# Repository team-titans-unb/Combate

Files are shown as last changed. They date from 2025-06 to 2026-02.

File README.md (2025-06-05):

# 🤖 Combate ⚔️

Bem-vindo ao repositório de documentação e firmware para robôs de combate da Equipe Titans! Este projeto organiza todas as informações técnicas, designs e códigos relacionados aos nossos robôs de combate categorizados por classes de peso. 🏗️💻

## 🗂️ Estrutura 

A seguir segue um exemplo da estrutura organizacional:
```
├── 🐞 Beetleweight/
│ ├── Robo_Alpha/
│ │ ├── 📄 Documentacao/
| | | ├── 📟 Eletrônica/
| | | ├── 📸 Imagens/
| | | └── ⚙️ Mecânica/
│ │ ├── 💾 Firmware/
│ │ └── 📌 README.md
│ └── Robo_Beta/
│ │ ├── 📄 Documentacao/
| | | ├── 📟 Eletrônica/
| | | ├── 📸 Imagens/
| | | └── ⚙️ Mecânica/
│ │ ├── 💾 Firmware/
│ │ └── 📌 README.md
├── 🐜 Antweight/
└── 📌 README.md (este arquivo)
```
## 🏷️ Categorias Disponíveis

Por enquanto, desevolvemos apenas robôs da categoria Beetleweight (1.36kg).
*(Pastas serão criadas conforme novos robôs forem desenvolvidos)* 🔄

## 🔧 Conteúdo Padrão por Robô

Cada robô deve ter documentado:
- 🧠 Firmware customizado
- 🔌 Esquemáticos eletrônicos
- 🛠️ 'Computer Aided Design' final renderizado

O README.md de cada diretório deve conter uma descrição curta das especificações do robô

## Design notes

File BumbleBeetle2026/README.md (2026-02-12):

# BumbleBeetle 2.0 (2026)
  
<p align="center">
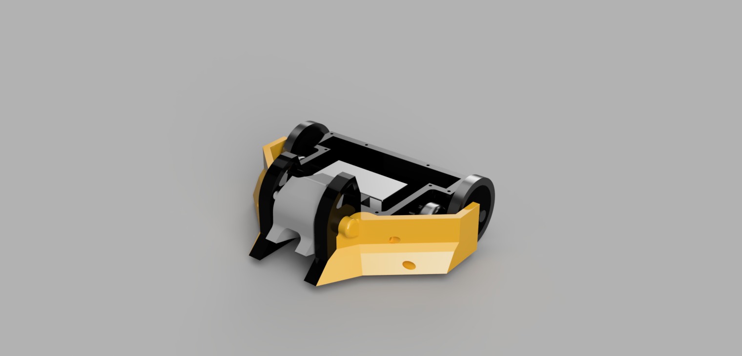
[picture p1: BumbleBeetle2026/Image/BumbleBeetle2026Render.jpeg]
  
</p>  

### ⚙️ Especificações Técnicas

- **Categoria:** Beetleweight (1,36kg)  
- **Arma:** Tambor giratório horizontal 70mm x 40mm
- **Motor da arma:** Surpass hobby C2830 - 750KV
- **Tração:** Rodas de PU55
- **Bateria:** FunFly 4S 100C 1550mAh

### 📟 Eletrônica

- **Rádio Controle:** -- 
- **Motor de Locomoção:** 2x Surpass Hobby 1700KV 
- **ESC da arma:** Flycolor Raptor5 50A
- **ESC de Locomoção:** --

### ⚡ Principais Características

- **Arma de aço 4340 temperado**
- Chassi Impresso de TPU

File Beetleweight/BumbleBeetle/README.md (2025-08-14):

# 🤖 Bumblebeetle - Beetleweight Combat Robot
  O projeto 'BumbleBeetle' é um robô de combate da categoria de 1.36kg. Tal projeto, é composto por uma pequena arma giratória caracterizada como DRUMS.  
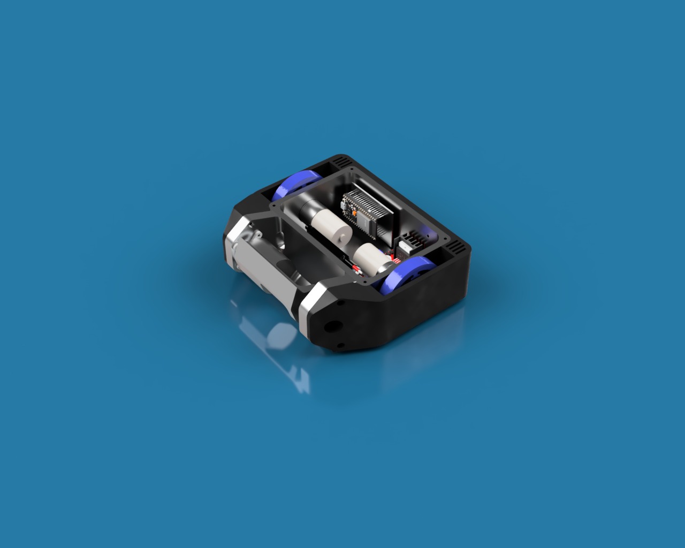
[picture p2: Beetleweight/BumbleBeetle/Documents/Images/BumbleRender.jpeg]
    

### ⚙️ Especificações Técnicas

- **Categoria:** Beetleweight (1,36kg)  
- **Arma:** Tambor giratório horizontal  
- **Motor da arma:** PropDrive 28-36 3000kv  
- **Tração:** 2 rodas de silocone  
- **Bateria:** LiPo 3S 11.1V 2200mAH

### 📟 Eletrônica

- **Microcontrolador:** ESP32 DevKit V1  
- **Controle:** Via Bluetooth usando um controle de PS3  
- **Motor de Locomoção:** 2x Motor com Caixa de Redução 12V 500RPM  
- **ESC:** Flysky Raptor5 50A

### ⚡ Principais Características

- **Arma de aço 1045 com têmpera**
- Chassi Impresso de TPU

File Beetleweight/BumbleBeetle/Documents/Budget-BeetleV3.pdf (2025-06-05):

Nome do item | Qtd | Valor Unitário | Taxa de Importação | Frete | Desconto | Custo Total | Observações | Outras Observações
Bateria Lipo 3s 2200mah | 1 | R$ 129,99 | R$ 0,00 | R$ 0,00 | R$ 0,00 | R$ 129,99 | | Este orçamento está sujeito a alterações
Usinagem da Arma | 1 | R$ 300,00 | R$ 0,00 | R$ 0,00 | R$ 0,00 | R$ 300,00 | Preço pode variar, mas é na faixa dos 300 reais | O corpo do robô será em alumínio 6065T
Filamento Tritan | 1 | R$ 219,84 | R$ 0,00 | R$ 0,00 | R$ 0,00 | R$ 219,84
Filamento TPU | 1 | R$ 119,90 | R$ 0,00 | R$ 0,00 | R$ 0,00 | R$ 119,90
ESC 60A BLHELI Brushless ReadyTosky | 1 | R$ 160,51 | R$ 0,00 | R$ 26,85 | R$ 0,00 | R$ 187,36 | Já comprado e valor com impostos
Carregador Duplo para Bateria Li-Ion 18650 | 1 | R$ 33,25 | R$ 0,00 | R$ 0,00 | R$ 0,00 | R$ 33,25 | Já comprado
Inscrição RCX | 1 | R$ 120,00 | R$ 0,00 | R$ 0,00 | R$ 0,00 | R$ 120,00 | Já comprado
Tarugo de aço 1045 | 1 | R$ 70,00 | R$ 0,00 | R$ 0,00 | R$ 0,00 | R$ 70,00 | Já comprado
Placa de Fibra de Vidro Universal (10 x 10 cm) Face Simples | 2 | R$ 13,23 | R$ 0,00 | R$ 0,00 | R$ 0,00 | R$ 26,46
Motor DC 12V | 2 | R$ 59,90 | R$ 0,00 | R$ 40,12 | R$ 8,00 | R$ 151,92 | Já comprado
Rolamento cerâmico VICAN | 1 | R$ 144,90 | R$ 0,00 | R$ 0,00 | R$ 0,00 | R$ 144,90 | Já comprado
| | | | | | Total
R$ 1.503,62

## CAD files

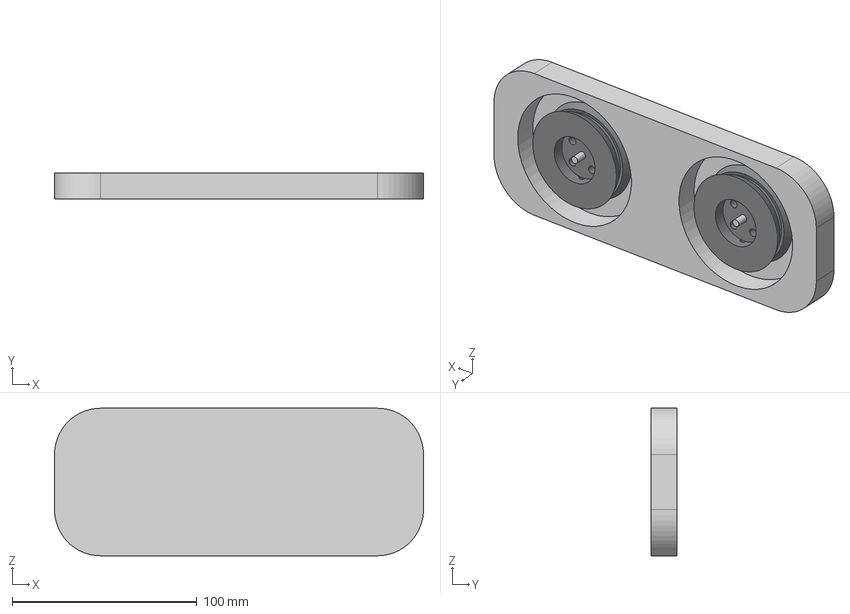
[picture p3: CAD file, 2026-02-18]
Beetleweight/BumbleBeetle/Documents/Mechanics/Molde das rodas Beetle 2025.step
200.0 x 14.0 x 80.0 mm
Nova Roda do Beetle em TPU e PU55
Nova Roda do Beetle em TPU e PU55 v8(Espelhar)

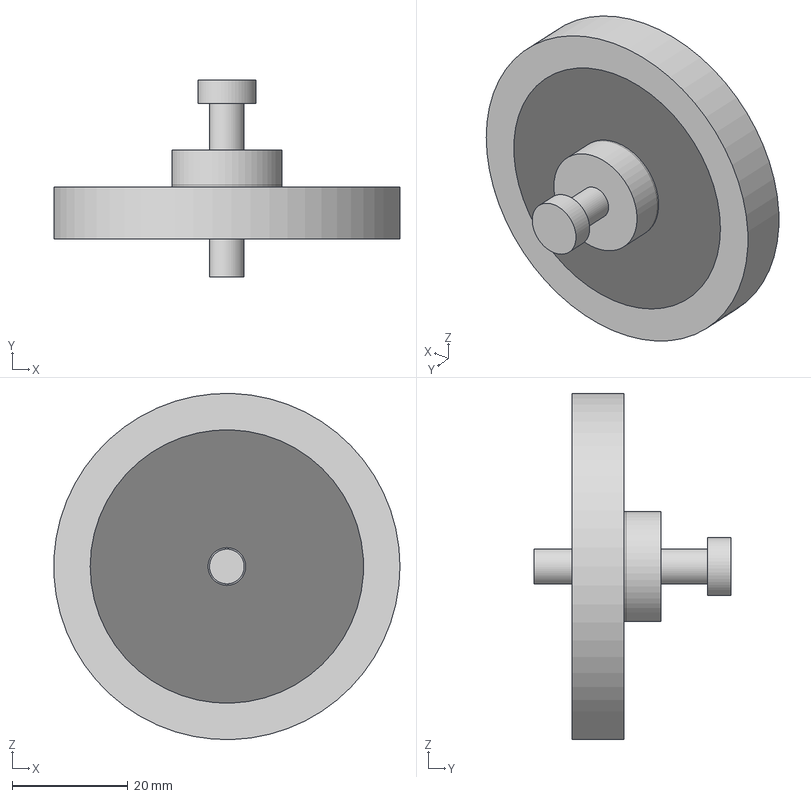
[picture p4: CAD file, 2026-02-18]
BumbleBeetle2026/Mechanic/Roda para loc. Tangenciada 2026.step
59.8 x 34.0 x 59.8 mm
ROLAMENTO 626 x 2

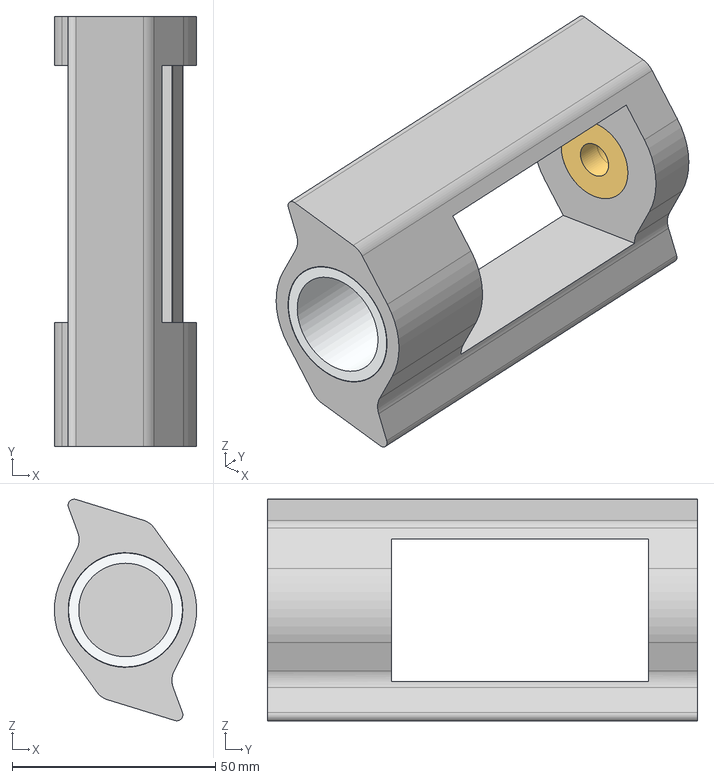
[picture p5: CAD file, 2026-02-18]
Beetleweight/BumbleBeetle/Documents/Mechanics/hubmotor 2025.step
35.0 x 105.7 x 54.5 mm
Imã do motor
rolamento 19 externo, 8 interno e 6 espessura x 2

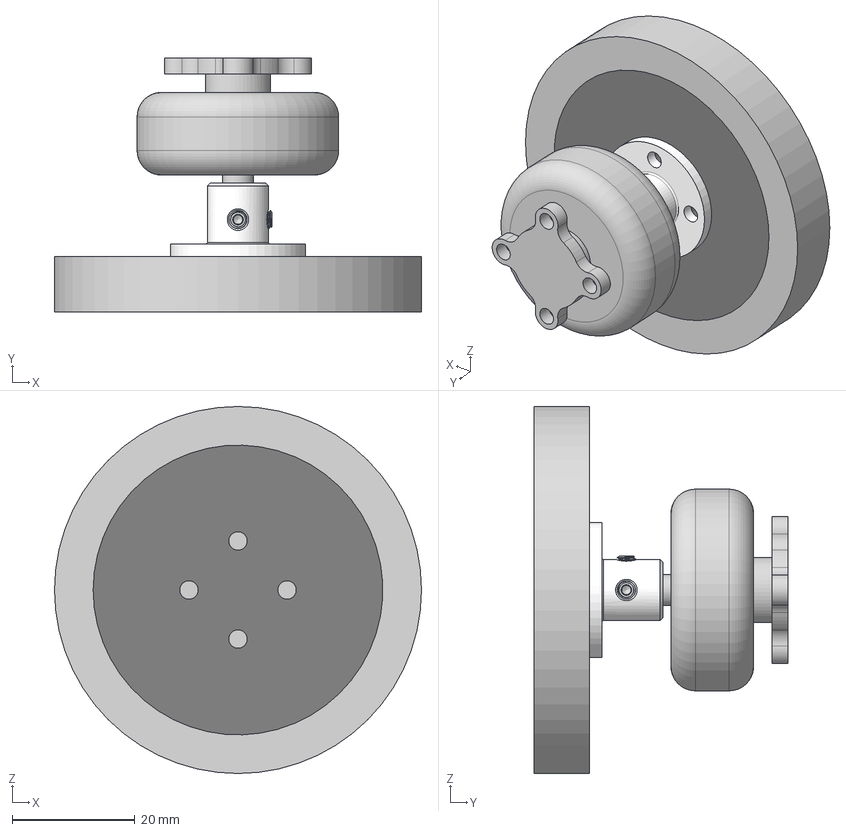
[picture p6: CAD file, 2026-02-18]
BumbleBeetle2026/Mechanic/Roda para Acoplador de eixo 2026.step
59.8 x 41.4 x 59.9 mm
91390A097 x 2
Surpass Hobby BAT 1700Kv

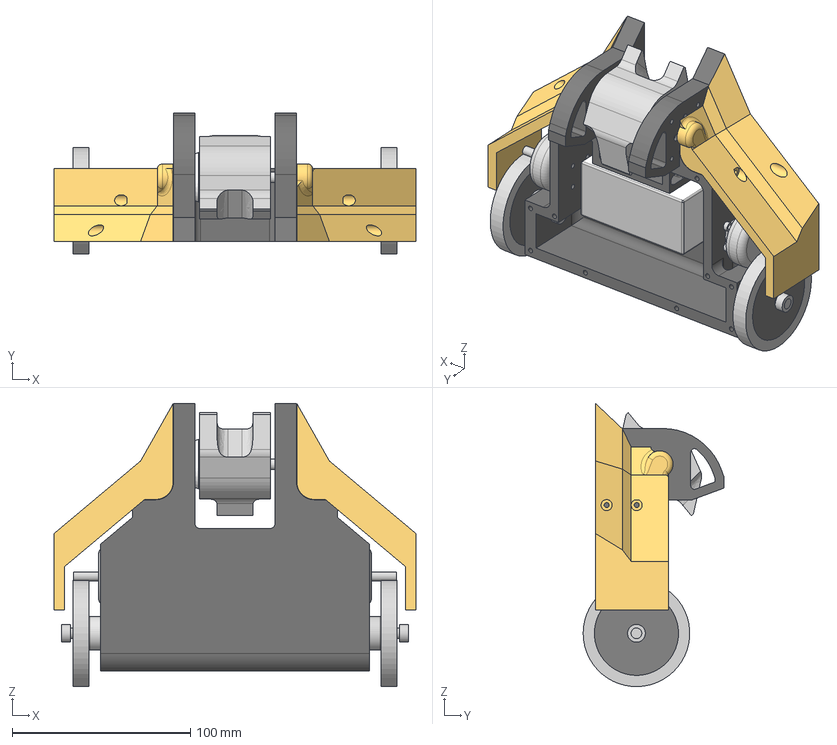
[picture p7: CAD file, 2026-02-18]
BumbleBeetle2026/Mechanic/Protótipo Plano A Loc. Tangenciado 2026.step
203.2 x 79.0 x 159.0 mm
Surpass Hobby BAT 1700Kv
FunFly 4S 1550mah
SURPASS HOBBY 2212 C2830 850KV_BRKT-01
SURPASS HOBBY 2212 C2830 850KV_BODY
SURPASS HOBBY 2212 C2830 850KV
ROLAMENTO 626 x 4
eixo retificado
Surpass Hobby BAT 1700Kv v4(Espelhar) (1)
ROLAMENTO 626 v1(Espelhar) x 2
Porca parafuso M6
Porca parafuso M6 v1(Espelhar)

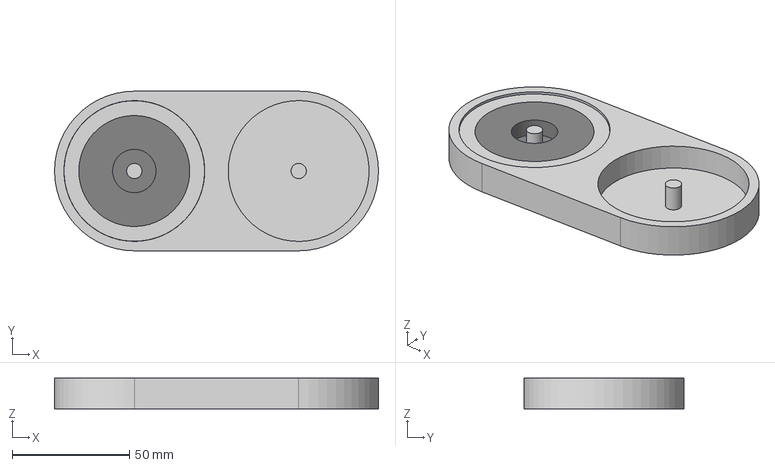
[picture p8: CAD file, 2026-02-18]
BumbleBeetle2026/Mechanic/Molde Para Loc Tangenciada (Imprimir em ABS!!)).step
138.0 x 68.0 x 13.0 mm

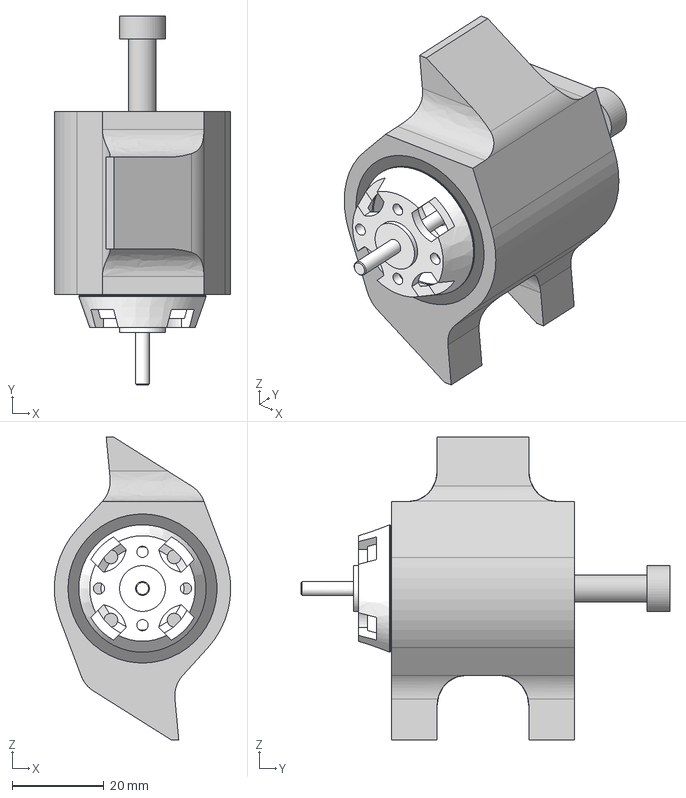
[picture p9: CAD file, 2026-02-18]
BumbleBeetle2026/Mechanic/HUBMOTOR bumbleBeetleV2 com novo motor 2026.step
38.5 x 80.5 x 66.0 mm
SURPASS HOBBY 2212 C2830 850KV_BODY
SURPASS HOBBY 2212 C2830 850KV
ROLAMENTO 626 x 2
eixo retificado

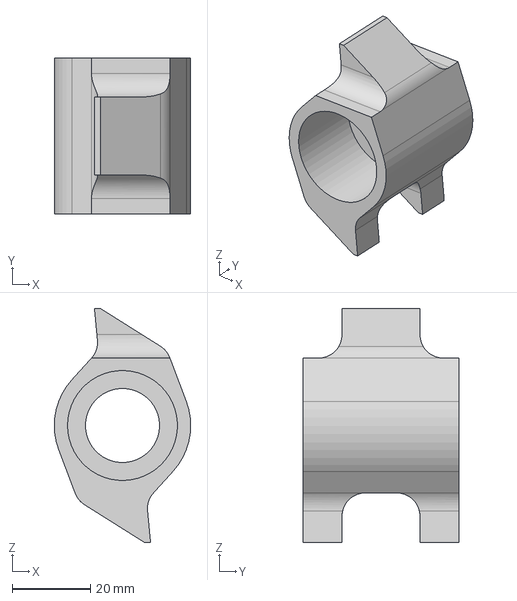
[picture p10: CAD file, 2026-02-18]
BumbleBeetle2026/Mechanic/HUBMOTOR bumble V2.step
35.0 x 40.0 x 60.0 mm

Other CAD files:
BumbleBeetle2026/Mechanic/Molde Para acoplador de eixo (Imprimir em ABS!!)).step

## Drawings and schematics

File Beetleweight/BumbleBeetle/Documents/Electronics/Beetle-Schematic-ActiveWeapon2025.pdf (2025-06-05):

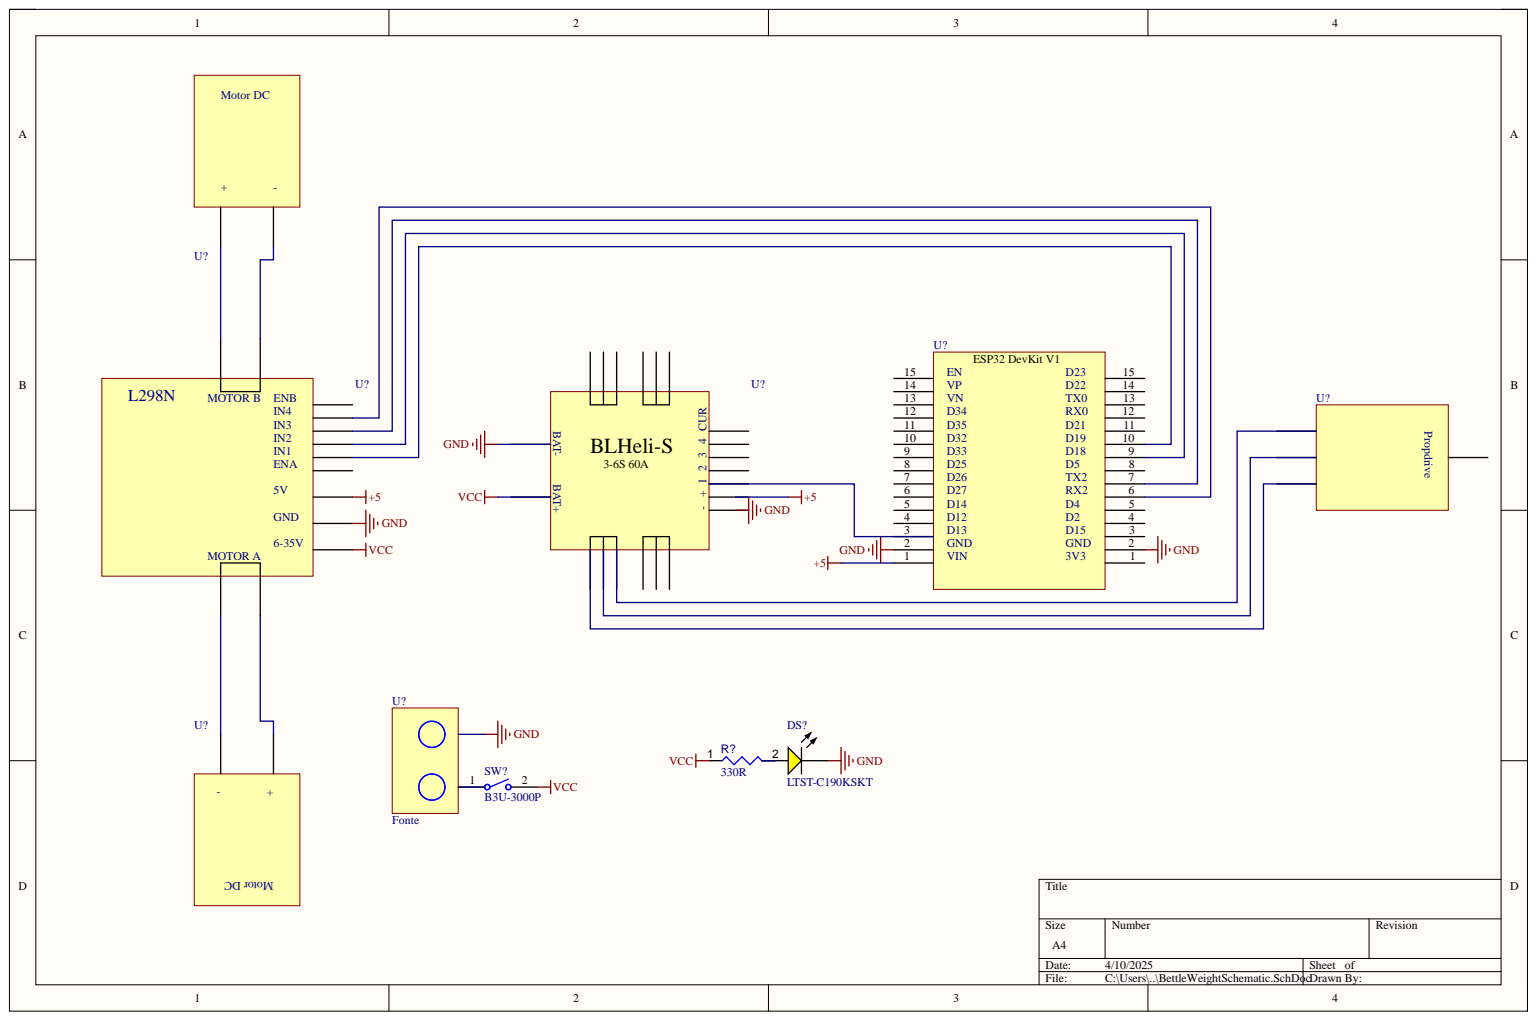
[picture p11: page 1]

D27 RX2 D14 D4 D12 D2 D13 D15 GND GND VI N 3V3

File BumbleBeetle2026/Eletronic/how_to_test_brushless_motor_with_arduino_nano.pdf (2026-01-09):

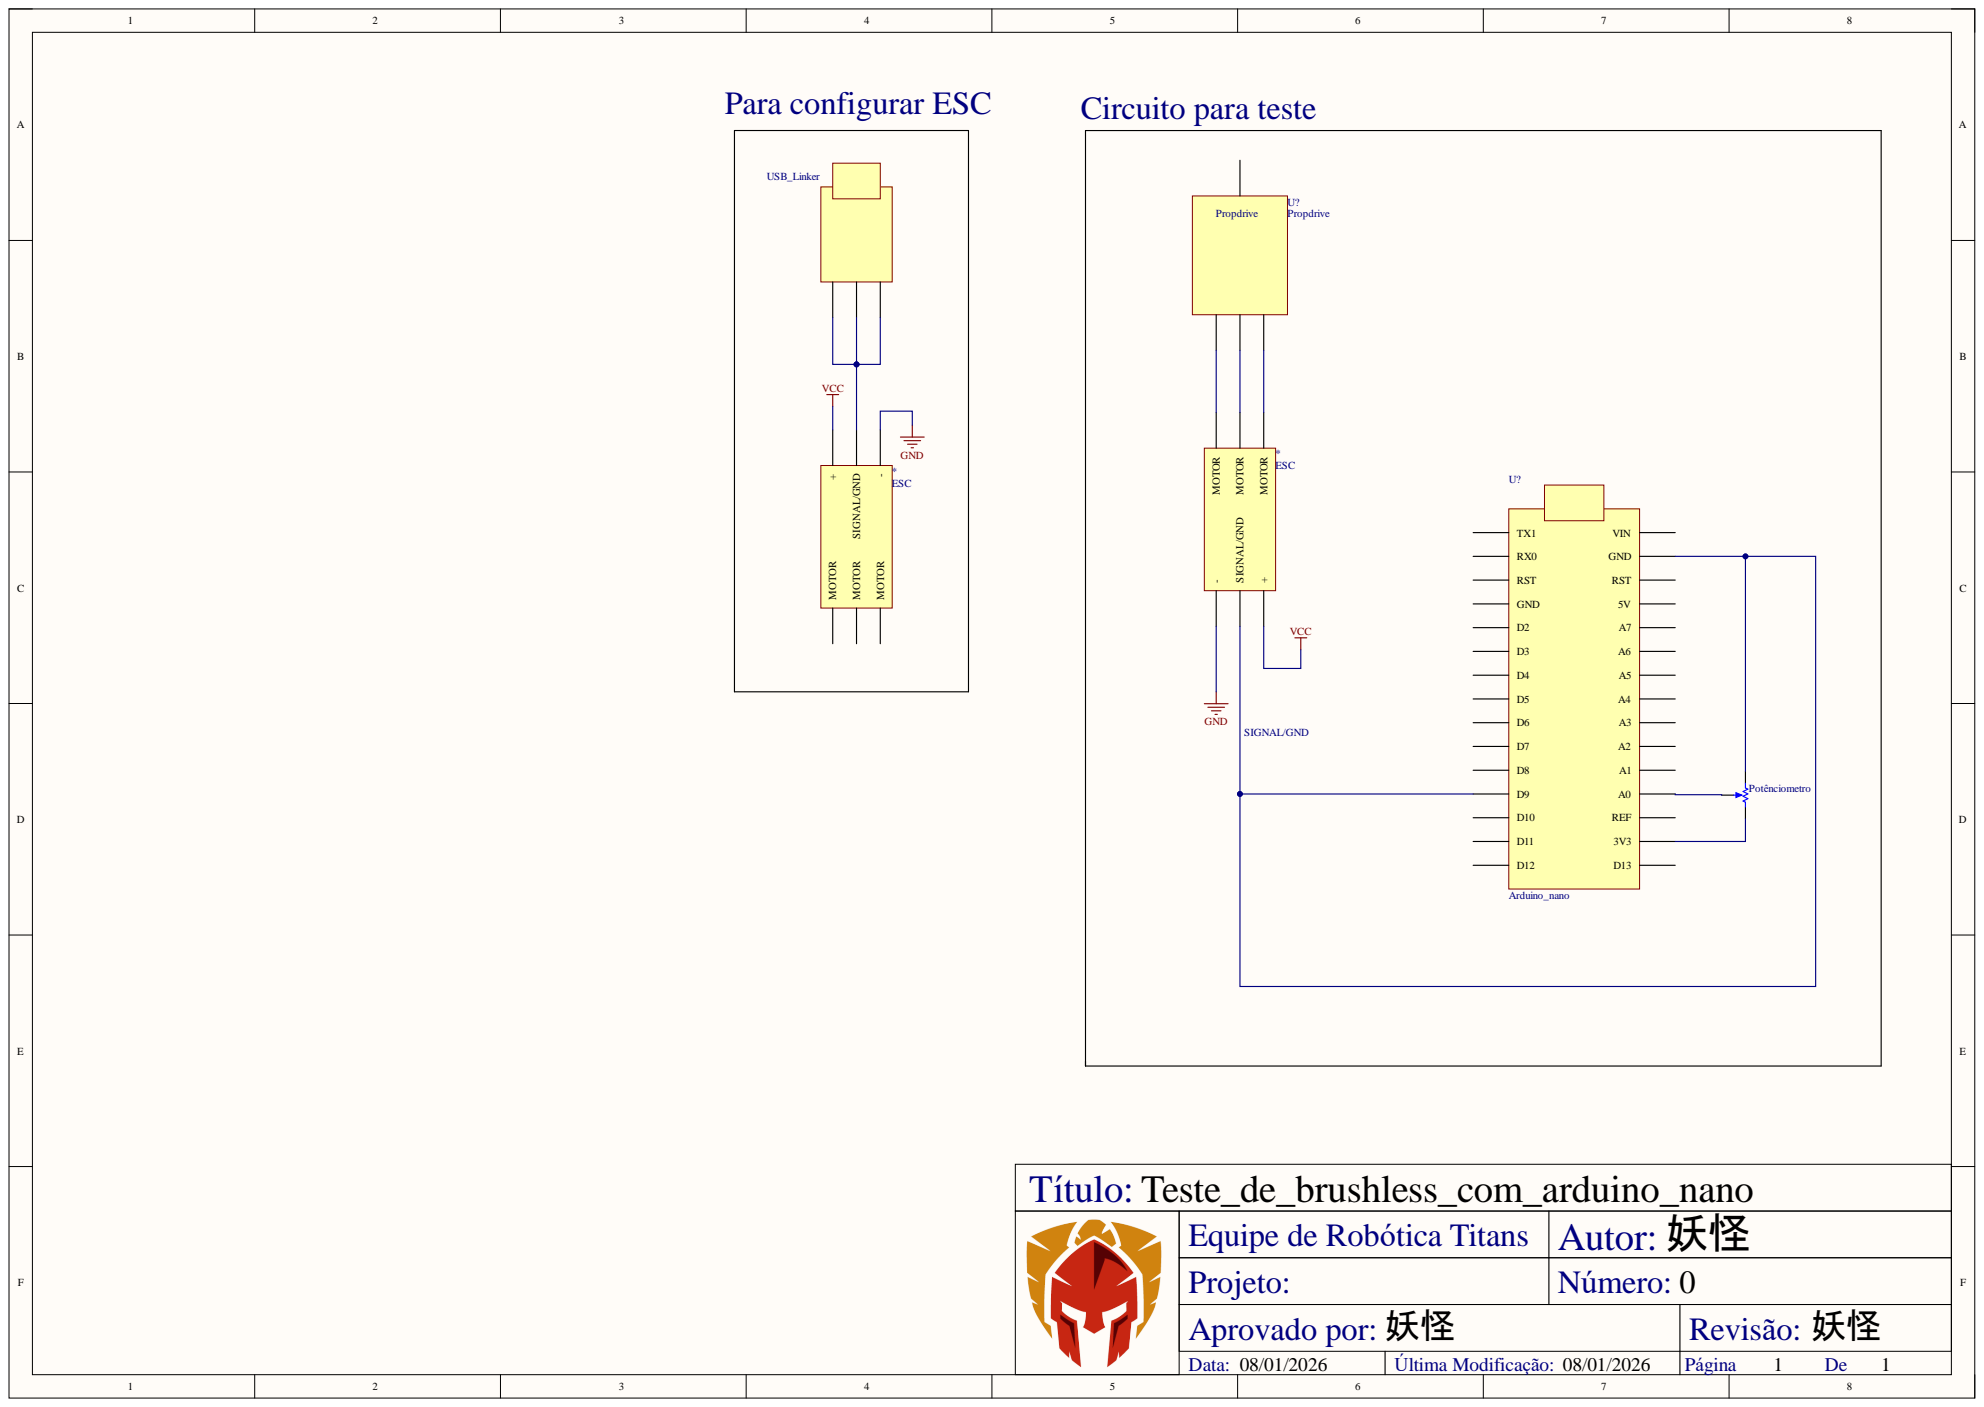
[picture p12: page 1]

m_arduino_nano 妖怪0 Equipe de Rob ótica T itans | Autor:

Projeto: | N ú mero:
妖怪 Aprovado por: | 妖怪 Revi s ão:

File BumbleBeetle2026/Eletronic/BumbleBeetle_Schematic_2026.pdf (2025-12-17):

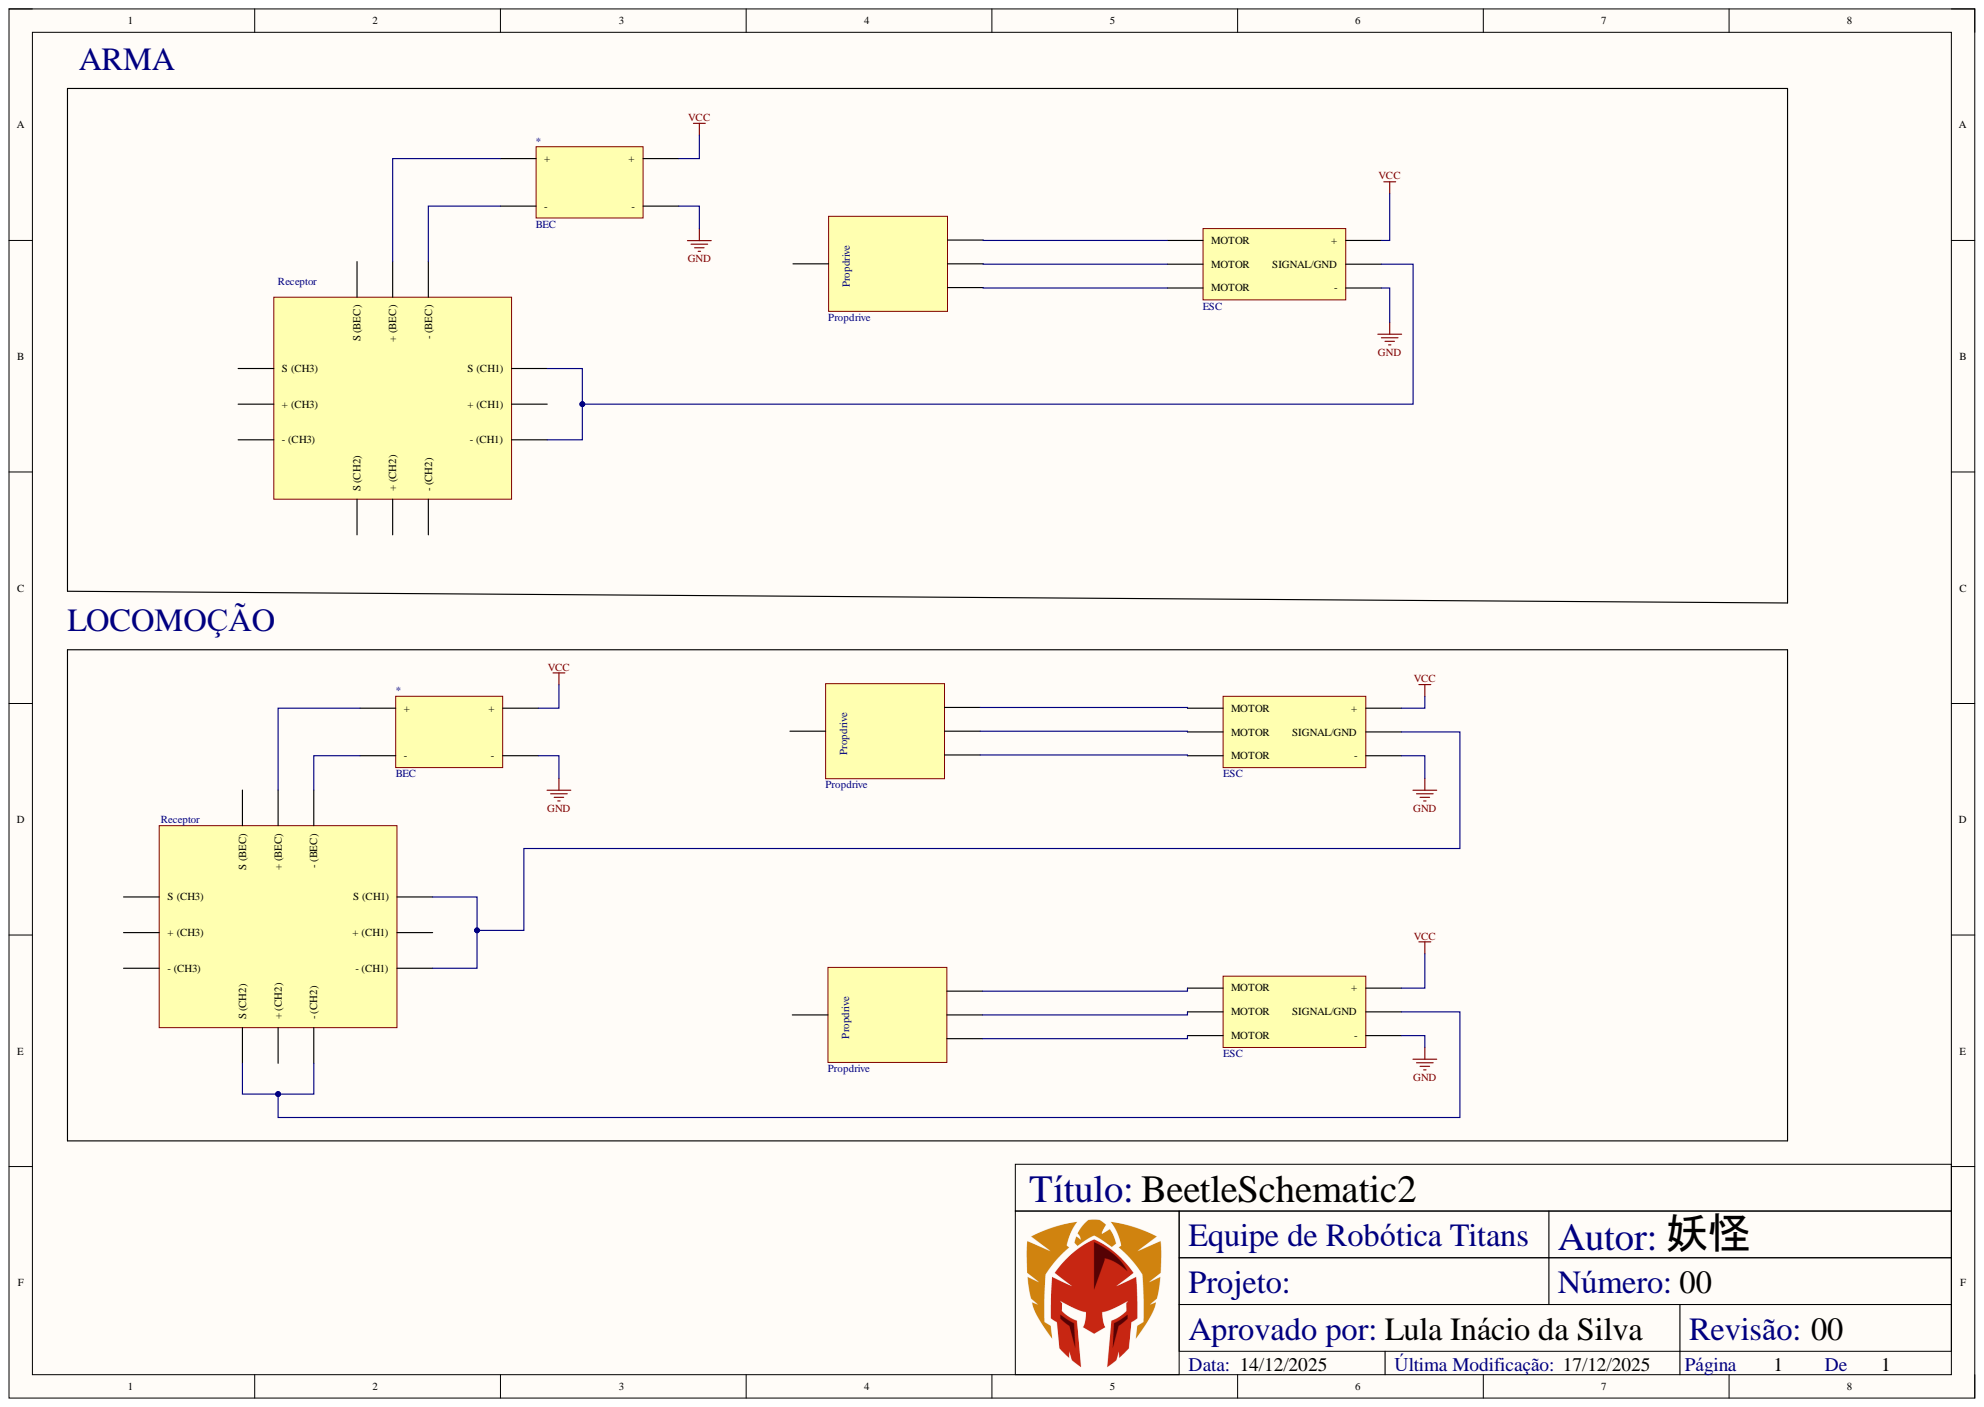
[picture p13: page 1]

Equipe de Robótica Titans | 妖怪 Autor:

Projeto: | Número: 00
Aprovado por: Lula Inácio da Silva | Revisão: 00

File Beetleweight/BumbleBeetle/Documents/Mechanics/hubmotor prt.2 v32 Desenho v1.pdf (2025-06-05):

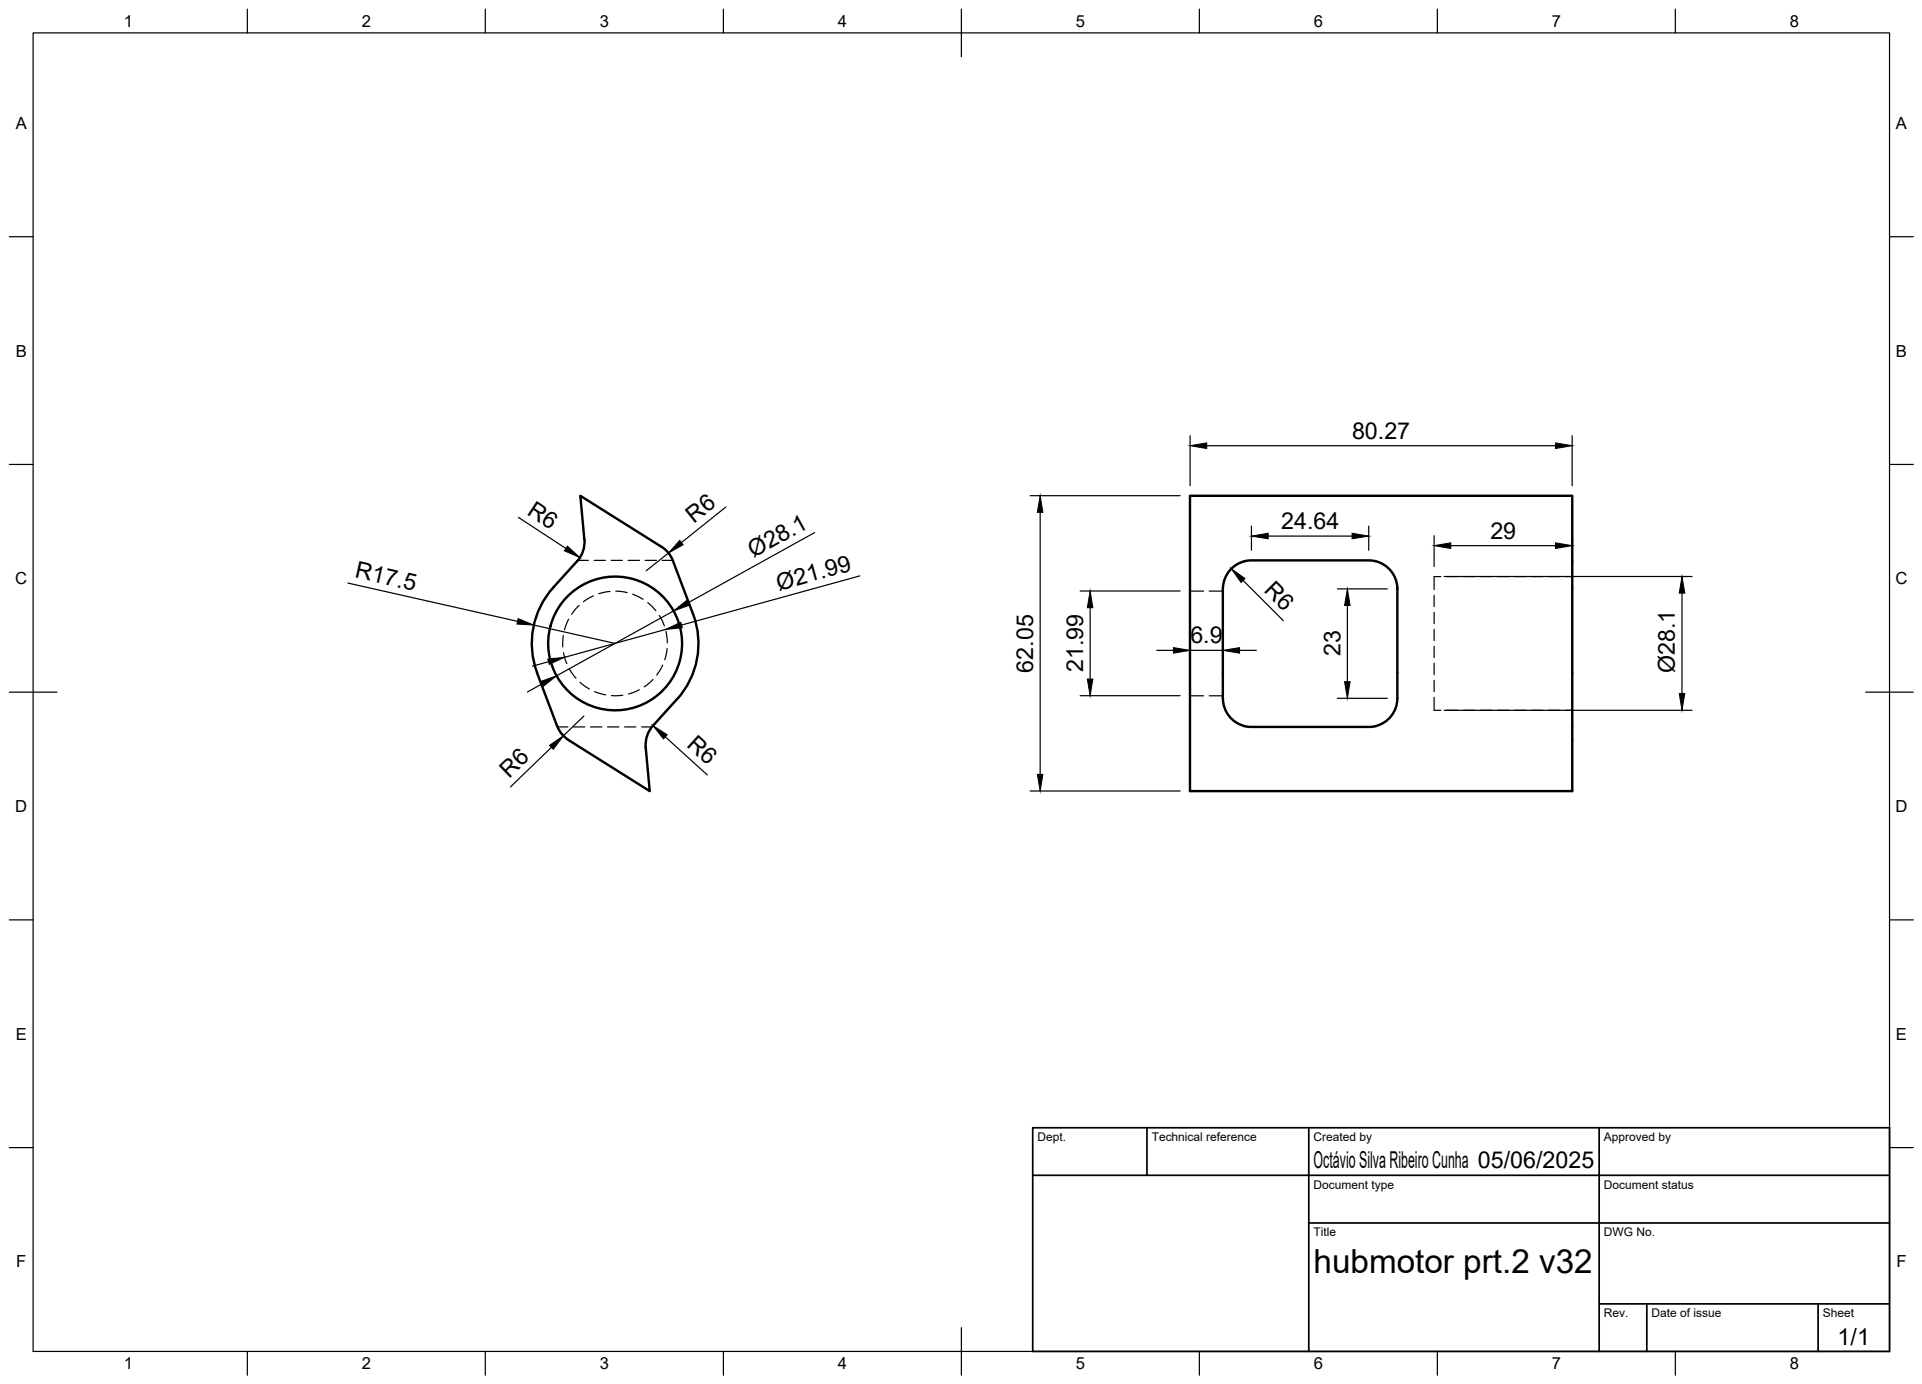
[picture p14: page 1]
Title; DWG No.; Rev.; Date of issue; Sheet; hubmotor prt.2 v32

Dept. | Technical reference | Created by Octávio Silva Ribeiro Cunha 05/06/2025 | Approved by

Document type | Document status

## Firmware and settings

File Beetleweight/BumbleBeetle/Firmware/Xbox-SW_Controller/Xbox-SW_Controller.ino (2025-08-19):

/*

Verifique se a versão da board da esp32 é a 2.0.17 ou inferior

Neste código foi-se utilizado uma "board" chamada BluePad32
Para instalar a board vá em File > Preferences e em "Aditional boards managers URLs" cole o link a seguir:
https://raw.githubusercontent.com/ricardoquesada/esp32-arduino-lib-builder/master/bluepad32_files/package_esp32_bluepad32_index.json

A board possui suporte para a maioria dos controles de videogame, teclados e mouses modernos como:
- Sony DualSense (PS5)
- Sony DualShock 4 (PS4)
- Sony DualShock 3 (PS3)
- Nintendo Switch Pro controller
- Nintendo Switch JoyCon
- Nintendo Wii U controller
- Nintendo Wii Remote + accessories
- Xbox Wireless controller (models 1708, 1914, adaptive)
- Android controllers
- Steam controller
- Stadia controller
- PC/Windows controller
- 8BitDo controllers
- Atari joystick
- iCade
- Mouse
- Keyboards
- DataFrog S80
*/ 

#include <Bluepad32.h>

// --- Pinos para o Motor Driver (H-Bridge) ---
// Motor 1 (Direito)
int RPWM_Output_1 = 18; // para frente 19, 18, 17, 16
int LPWM_Output_1 = 19; // para trás

// Motor 2 (Esquerdo)
int RPWM_Output_2 = 16; // para frente
int LPWM_Output_2 = 17; // para trás

// --- Configurações de PWM para os motores DC ---
const int freq = 5000;
const int resolution = 8; 
// Canais PWM
const int rChannel_1 = 0;
const int lChannel_1 = 1;
const int rChannel_2 = 2;
const int lChannel_2 = 3;

// --- Configurações para o ESC ---
const int escPin = 13;
const int escChannel = 4;
const int escFreq = 60; // Frequência comum para ESCs
int velocidadeEscMin = 75;  // Valor PWM mínimo (parado)
int velocidadeEscMax = 120; // Valor PWM máximo
int velocidadeEscAtual = velocidadeEscMin; // Velocidade atual
bool estadoMotorEsc = false; // false = desligado, true = ligado
bool r2PressedLast = false;   // Para detectar mudança no botão R2

// --- Objeto para o controle ---
ControllerPtr myController;

// --- Protótipo da função de controle dos motores ---
void driveMotor(int motorNum, int speed);

void onConnectedController(ControllerPtr ctl) {
    if (myController == nullptr) {
        myController = ctl;
        Serial.println("Controle conectado!");
    }
}

void onDisconnectedController(ControllerPtr ctl) {
    if (myController == ctl) {
        myController = nullptr;
        Serial.println("Controle desconectado!");
    }
}

void setup() {
    Serial.begin(115200);

    // --- Configuração dos canais PWM para os motores DC ---
    ledcSetup(rChannel_1, freq, resolution);
    ledcSetup(lChannel_1, freq, resolution);
    ledcSetup(rChannel_2, freq, resolution);
    ledcSetup(lChannel_2, freq, resolution);

    // --- Associa os pinos aos canais PWM ---
    ledcAttachPin(RPWM_Output_1, rChannel_1);
    ledcAttachPin(LPWM_Output_1, lChannel_1);
    ledcAttachPin(RPWM_Output_2, rChannel_2);
    ledcAttachPin(LPWM_Output_2, lChannel_2);

    // --- Configuração do canal PWM para o ESC ---
    ledcSetup(escChannel, escFreq, resolution);
    ledcAttachPin(escPin, escChannel);
    ledcWrite(escChannel, velocidadeEscMin); // Garante que o ESC comece desligado

    // --- Inicialização do Bluepad32 ---
    BP32.setup(&onConnectedController, &onDisconnectedController);
    BP32.forgetBluetoothKeys();
    
    Serial.println("=== SISTEMA PRONTO ===");
    Serial.println("Controles:");
    Serial.println("R2 (Trigger direito): Ativa/Desativa arma");
    Serial.println("L2: Aumenta velocidade arma");
    Serial.println("----------------------");
    printStatusArma();
}

void loop() {
    BP32.update();

    if (myController && myController->isConnected()) {
        // Controle do ESC com R2
        bool r2Pressed = (myController->throttle() > 0);
        if (r2Pressed && !r2PressedLast) {
            estadoMotorEsc = !estadoMotorEsc;
            if (estadoMotorEsc) {
                velocidadeEscAtual = velocidadeEscMin + 5;
                Serial.println(">> ARMA LIGADA <<");
            } else {
                velocidadeEscAtual = velocidadeEscMin;
                Serial.println(">> ARMA DESLIGADA <<");
            }
            ledcWrite(escChannel, velocidadeEscAtual);
            printStatusArma();
        }
        r2PressedLast = r2Pressed;

        // Aumentar velocidade com L2
        if (estadoMotorEsc && myController->brake() > 0) {
            velocidadeEscAtual = constrain(velocidadeEscAtual + 1, velocidadeEscMin, velocidadeEscMax);
            ledcWrite(escChannel, velocidadeEscAtual);
            Serial.println("L2: ↑ Aumentando velocidade arma ↑");
            printStatusArma();
            delay(100);
        }

        // Movimento com botões e analógicos
        if (myController->buttons() & 0x1000) {  // Quadrado: gira direita
            driveMotor(1, -150);
            driveMotor(2, 150);
        } else if (myController->buttons() & 0x2000) {  // Bola: gira esquerda
            driveMotor(1, 150);
            driveMotor(2, -150);
        } else {
            int velocidadeFrente = -map(myController->axisY(), -512, 511, -255, 255);
            int velocidadeLado = map(myController->axisRX(), -512, 511, 255, -255);

            if (myController->buttons() & 0x100) {  // Triângulo: debug
                Serial.println(velocidadeFrente);
                Serial.println("velocidadeFrente");
                Serial.println(velocidadeLado);
                Serial.println("velocidadelado");
                Serial.println("*************");
            }

            int velMotorDireito = velocidadeFrente - velocidadeLado;
            int velMotorEsquerdo = velocidadeFrente + velocidadeLado;

            int maxVal = max(abs(velMotorDireito), abs(velMotorEsquerdo));
            if (maxVal > 255) {
                velMotorDireito = (velMotorDireito * 255) / maxVal;
                velMotorEsquerdo = (velMotorEsquerdo * 255) / maxVal;
            }

            driveMotor(1, velMotorDireito);
            driveMotor(2, velMotorEsquerdo);

            Serial.print("Motor D: ");
            Serial.print(velMotorDireito);
            Serial.print(" | Motor E: ");
            Serial.println(velMotorEsquerdo);
        }

    } else {
        // CONTROLE DESCONECTADO: PARAR TUDO!
        driveMotor(1, 0);
        driveMotor(2, 0);

        if (estadoMotorEsc) {
            velocidadeEscAtual = velocidadeEscMin;
            ledcWrite(escChannel, velocidadeEscAtual);
            estadoMotorEsc = false;
            Serial.println(">> CONTROLE DESCONECTADO: ARMA DESLIGADA POR SEGURANÇA <<");
            printStatusArma();
        }
    }
}

// Função para imprimir status da arma
void printStatusArma() {
    Serial.print("Status arma: ");
    Serial.print(estadoMotorEsc ? "LIGADA" : "DESLIGADA");
    Serial.print(" | Velocidade: ");
    Serial.print(velocidadeEscAtual);
    Serial.print(" (");
    Serial.print(map(velocidadeEscAtual, velocidadeEscMin, velocidadeEscMax, 0, 100));
    Serial.println("%)");
    Serial.println("----------------------");
}

// Função para controle dos motores DC
void driveMotor(int motorNum, int speed) {
    if (motorNum == 2) {
        speed = -speed;  // Inverte sentido do motor esquerdo para corrigir direção
    }

    int absSpeed = abs(speed);
    int finalSpeed = constrain(absSpeed, 0, 255);

    int rPwmChannel, lPwmChannel;

    if (motorNum == 1) {  // Motor direito
        rPwmChannel = rChannel_1;
        lPwmChannel = lChannel_1;
    } else {  // Motor esquerdo
        rPwmChannel = rChannel_2;
        lPwmChannel = lChannel_2;
    }

    if (speed > 20) {  // Para frente
        ledcWrite(rPwmChannel, finalSpeed);
        ledcWrite(lPwmChannel, 0);
    } else if (speed < -20) {  // Para trás
        ledcWrite(rPwmChannel, 0);
        ledcWrite(lPwmChannel, finalSpeed);
    } else {  // Parado
        ledcWrite(rPwmChannel, 0);
        ledcWrite(lPwmChannel, 0);
    }
}

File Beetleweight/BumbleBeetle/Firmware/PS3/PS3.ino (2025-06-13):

#include <Ps3Controller.h>

// --- Pinos para o Motor Driver (H-Bridge) ---
// Motor 1 (Direito)
int RPWM_Output_1 = 18; // para frente 19, 18, 17, 16
int LPWM_Output_1 = 19; // para trás

// Motor 2 (Esquerdo)
int RPWM_Output_2 = 16; // para frente
int LPWM_Output_2 = 17; // para trás

// --- Configurações de PWM para os motores DC ---
const int  freq = 5000;
const int  resolution = 8; 
// Canais PWM
const int  rChannel_1 = 0;
const int  lChannel_1 = 1;
const int  rChannel_2 = 2;
const int  lChannel_2 = 3;

// --- Configurações para o ESC ---
const int  escPin = 13;
const int  escChannel = 4;
const int  escFreq = 60; // Frequência comum para ESCs
int velocidadeEscDesligado = 75; // Valor PWM para o ESC parado
int velocidadeEscLigado = 90;    // Valor PWM para o ESC em baixa rotação
bool estadoMotorEsc = false;   // false = desligado, true = ligado

// --- Protótipo da função de controle dos motores ---
void driveMotor(int motorNum, int speed);

void setup() {
  Serial.begin(115200);

  // --- Configuração dos canais PWM para os motores DC ---
  ledcSetup(rChannel_1, freq, resolution);
  ledcSetup(lChannel_1, freq, resolution);
  ledcSetup(rChannel_2, freq, resolution);
  ledcSetup(lChannel_2, freq, resolution);

  // --- Associa os pinos aos canais PWM ---
  ledcAttachPin(RPWM_Output_1, rChannel_1);
  ledcAttachPin(LPWM_Output_1, lChannel_1);
  ledcAttachPin(RPWM_Output_2, rChannel_2);
  ledcAttachPin(LPWM_Output_2, lChannel_2);

  // --- Configuração do canal PWM para o ESC ---
  ledcSetup(escChannel, escFreq, resolution);
  ledcAttachPin(escPin, escChannel);
  ledcWrite(escChannel, velocidadeEscDesligado); // Garante que o ESC comece desligado

  // --- Inicialização do Controle PS3 ---
  Ps3.begin("74:85:76:73:65:71"); 
  Serial.println("Aguardando conexão do controle PS3...");
}

void loop() {
  if (Ps3.isConnected()) {
    // --- Controle do Motor com ESC (Liga/Desliga) ---
    if (Ps3.event.button_down.l2) {
      estadoMotorEsc = !estadoMotorEsc;
      if (estadoMotorEsc) {
        ledcWrite(escChannel, velocidadeEscLigado);
        Serial.println("Motor ESC LIGADO");
      } else {
        ledcWrite(escChannel, velocidadeEscDesligado);
        Serial.println("Motor ESC DESLIGADO");
      }
    }

    // --- Controle de Movimento do Robô ---
    if (Ps3.data.button.square) {
      driveMotor(1, 150);
      driveMotor(2, -150);
    } else if (Ps3.data.button.circle) {
      driveMotor(1, -150);
      driveMotor(2, 150);
    } else {
      int velocidadeFrente = map(Ps3.data.analog.stick.ly, -128, 127, 255, -255);
      int velocidadeLado = map(Ps3.data.analog.stick.rx, -128, 127, -255, 255);
      if (Ps3.data.button.triangle){
      Serial.println(velocidadeFrente);
      Serial.println("velocidadeFrente");//apagar
      Serial.println(velocidadeLado);
      Serial.println("velocidadelado");
      Serial.println("*************");}

      int velMotorDireito;
      int velMotorEsquerdo;

      if (velocidadeFrente > 20 && velocidadeLado > 20) { // Frente e virando para a direita
        velMotorDireito = velocidadeLado / 2; //tornar a curva suave 
        velMotorEsquerdo = velocidadeFrente / 1.5;
      } else if (velocidadeFrente > 20 && velocidadeLado < -20) { // Frente e virando para a esquerda
        velMotorDireito = velocidadeFrente / 1.5;
        velMotorEsquerdo = velocidadeLado / 2;
      } else if (velocidadeFrente < -20 && velocidadeLado > 20) { // Ré e virando para a direita
        velMotorDireito = -velocidadeLado / 2;
        velMotorEsquerdo = velocidadeFrente/1.5;
      } else if (velocidadeFrente < -20 && velocidadeLado < -20) { // Ré e virando para a esquerda
        velMotorDireito = velocidadeFrente / 2;
        velMotorEsquerdo = -velocidadeLado / 1.5;
      } else if (abs(velocidadeFrente) > 20 && abs(velocidadeLado) <= 20) { // Apenas frente ou trás em linha reta
        velMotorDireito = velocidadeFrente;//subtrair 50 do motor mais forte para ir em linha reta (?)
        velMotorEsquerdo = velocidadeFrente;
      } else if (abs(velocidadeFrente) <= 20 && abs(velocidadeLado) > 20) {// Giro no próprio eixo
        velMotorDireito = -velocidadeLado;
        velMotorEsquerdo = velocidadeLado;
      } else {
        // Parado
        velMotorDireito = 0;
        velMotorEsquerdo = 0;
      }

      velMotorDireito = constrain(velMotorDireito, -255, 255);
      velMotorEsquerdo = constrain(velMotorEsquerdo, -255, 255);

      Serial.println("direção do motor direito");
      Serial.println(velMotorDireito);
      Serial.println("direção do motor esquerdo");
      Serial.println(velMotorEsquerdo);

      driveMotor(1, velMotorDireito);
      driveMotor(2, velMotorEsquerdo);
    }
  } else {
    driveMotor(1, 0);
    driveMotor(2, 0);
    if (estadoMotorEsc) {
      ledcWrite(escChannel, velocidadeEscDesligado);
      estadoMotorEsc = false;
    }
  }
}

// O número do motor (1 para direito, 2 para esquerdo).
// A velocidade e direção (-255 a 255). Negativo para ré, Positivo para frente, 0 para parar.
void driveMotor(int motorNum, int speed) {
  int absSpeed = abs(speed);
  int finalSpeed = constrain(absSpeed, 0, 255);

  int rPwmChannel, lPwmChannel;

  if (motorNum == 1) {
    rPwmChannel = rChannel_1;
    lPwmChannel = lChannel_1;
  } else {
    rPwmChannel = rChannel_2;
    lPwmChannel = lChannel_2;
  }

  if (speed > 20) {
    ledcWrite(rPwmChannel, finalSpeed);
    ledcWrite(lPwmChannel, 0);
  } else if (speed < -20) {
    ledcWrite(rPwmChannel, 0);
    ledcWrite(lPwmChannel, finalSpeed);
  } else {
    ledcWrite(rPwmChannel, 0);
    ledcWrite(lPwmChannel, 0);
  }
}

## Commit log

2025-06-10 criando pasta do firmware para organização
    criando pasta e adicionando codigo prototipo_beelte.ino
2025-06-11 controle de ps3 para o bumblebeetle
    esse é o codigo de ps3 para controlar o bumblebeetle, ainda faltam ajustes de responsividade e curvas suaves
2025-06-11 Update PS3.ino
    novo codigo para controle de ps3
2025-06-13 Create ButtonsTest
    referencia do codigo dos botoes e da bateria
2025-06-13 Update PS3.ino
    Alteração na lógica de locomoção (dividindo em partes para calibrar movimentos mais facilmente)
2025-08-19 Add Xbox/Switch controller firm
2026-01-09 Add files via upload
    o USB linker deve estar conectado a um computador para flashar o ESC com as configurações que forem de preferência do utilizador. também deve ser fornecido no mínimo 5V externos a ESC para que os par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
    para a montagem de teste do ESC, é recomendado fazer em uma protoboard.
    os materiais utilizados seriam: protoboard, arduino nano, potenciômetro, ESC, bateria, motor e fios para as conexões.
2026-01-09 Código para teste de motores com ESC em arduino nano
2026-02-09 Create Código para teste de motores com ESC em um arduino nano
